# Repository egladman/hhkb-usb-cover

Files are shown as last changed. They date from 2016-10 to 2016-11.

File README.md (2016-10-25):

# HHKB USB Cover

[3D View](https://github.com/egladman/hhkb-usb-cover/blob/master/usb_cover.stl)

<br>

This is a cover for each of the unused usb ports on the Happy Hacking Keyboard with Hasu's controller.

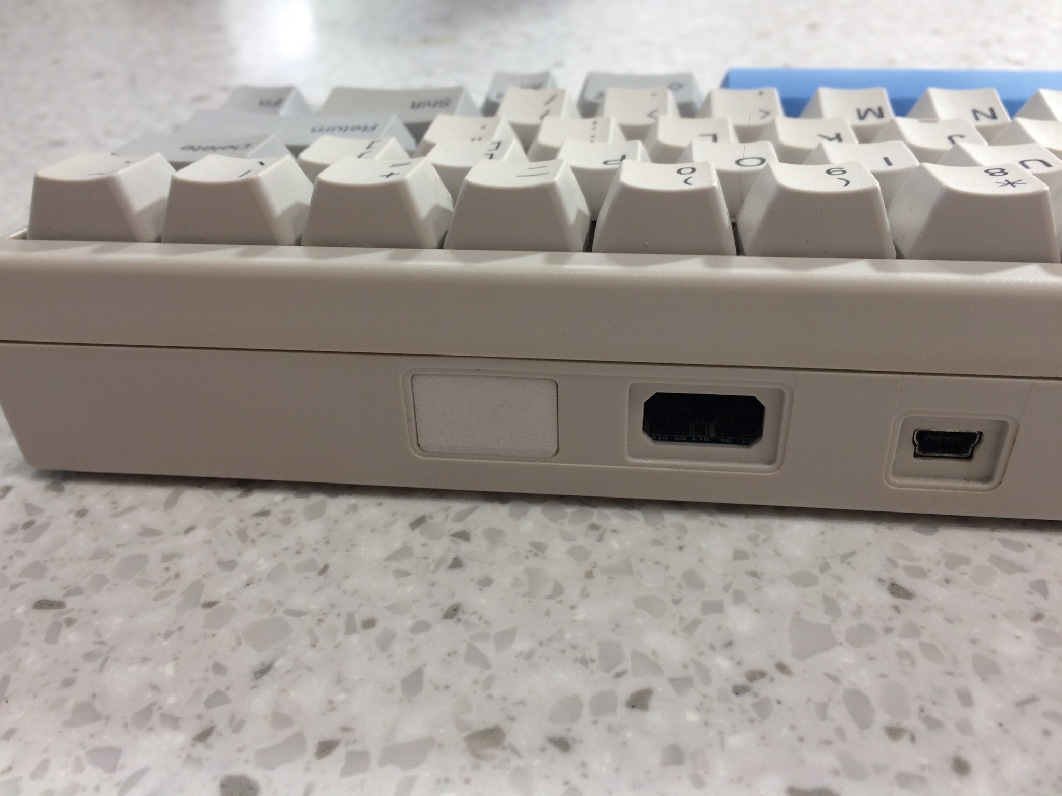
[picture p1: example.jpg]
HHKB USB Cover


<br>

Contributions/Suggestions are welcome!

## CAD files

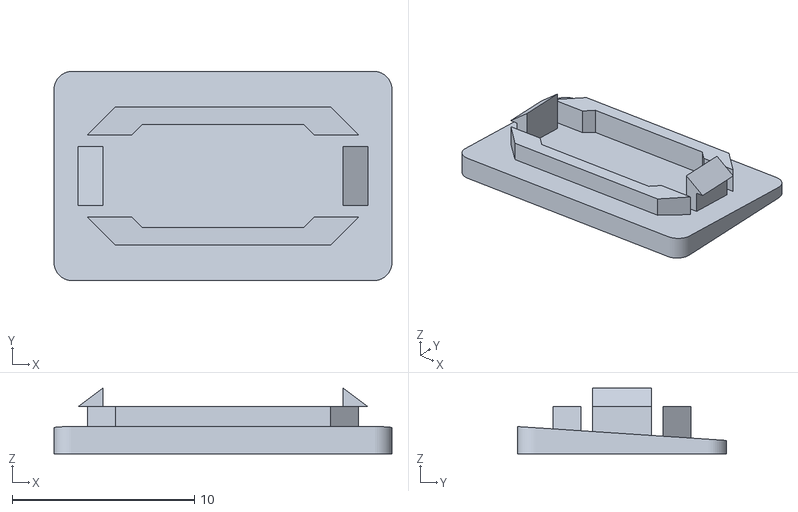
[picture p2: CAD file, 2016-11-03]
usb_cover.stl
18.6 x 11.5 x 3.61

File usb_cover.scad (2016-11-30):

outerWidth = 18.56;
outerHeight = 11.49;

innerWidth = 14.90;
innerHeight = 7.57;

widthDiff = (outerWidth - innerWidth)/2;
heightDiff = (outerHeight - innerHeight)/2;

radius = 1;

plugDepth = 1.75; 

translate([0,outerHeight,.85])
rotate([90,0,0])
cover();

module cover(){
difference() {
  $fn=50;
  translate([radius,0,radius])
  minkowski() {
   cube([outerWidth-(radius * 2),1.70, outerHeight- (radius * 2)], 0);

   rotate([90,0,0])
   cylinder(r=radius,h=1.70, center=true);
  }

  translate([(outerWidth-1)/2,2.10,outerHeight/2])
  rotate([-3.8,0,0])
  cube([outerWidth+2,3.65, outerHeight+10], center=true);
}

translate([widthDiff-.5,plugDepth,(outerHeight/2)])
clip();

translate([-widthDiff+.5+outerWidth,plugDepth,(outerHeight/2)])
rotate([0,180,0])
clip();

difference() {
  octogon();
    
  translate([outerWidth/8,0,outerHeight/8])
  scale(0.75)
  resize([0,10,0])
  octogon();
 
  translate([outerWidth/2,1.75,outerHeight/2])
  cube([13.2, 5, 3.5], center=true);
    
  translate([outerWidth/2,1.75,(outerHeight/2)+1.935])
  cube([16, 5, .625], center=true);
    
  translate([outerWidth/2,1.75,(outerHeight/2)-1.935])
  cube([16, 5, .625], center=true);
}


}

module octogon(){
  difference() {
    translate([widthDiff,0,heightDiff])
    cube([innerWidth,plugDepth, innerHeight], 0);

    len = 2.18;

    translate([widthDiff,0,heightDiff])
    rotate([0,45,0])
    cube([len, 25, len], center=true);

    translate([widthDiff,0,heightDiff+innerHeight])
    rotate([0,45,0])
    cube([len, 25, len], center=true);

    translate([widthDiff+innerWidth,0,heightDiff+innerHeight])
    rotate([0,45,0])
    cube([len, 25, len], center=true);

    translate([widthDiff+innerWidth,0,heightDiff])
    rotate([0,45,0])
    cube([len, 25, len], center=true);
  }
}

module clip(){
  difference(){
    resize([2,1.5,3.25])
    rotate([90,0,90])
    polyhedron ( points = [[0, -1, 3], [0, 1, 3], [0, 1, 0], [0, -1, 0], [3, -1, 3], [3, 1, 3]], 
    faces = [[0,3,2], [0,2,1], [3,0,4], [1,2,5], [0,5,4], [0,1,5],  [5,2,4], [4,2,3], ]);
  
    translate([3.35,0,0])
    cube([4, 4, 10], center=true);  
  }
}

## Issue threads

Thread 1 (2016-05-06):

add retaining clips to plug

egladman, 2016-05-06:
it would be great if I added some sort of retaining clips to the plugs to ensure they stay flush with the case

egladman, 2016-10-25:
so after printing this once i no longer think that retaining clips are needed.

egladman, 2016-10-28:
i ended up adding them 2b2ae7a7a53ebdc9f9e6a21ebc16ebe4d2ef6ed8

Closed 2016-10-25.

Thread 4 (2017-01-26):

What material to use?

rvanginneken, 2017-01-26:
Hey egladman,

I'm about to send this to a 3D printer, but I'm wondering what material you'd advise to use? Currently I'm looking at "rubber-like".

Also, can you give some info how snug it will fit? I'm using the board on different places and the covers need to stay in place. They should be removable somehow tho, to get to the reset button.

Looking forward to your feedback!

egladman, 2017-01-27:
I've had success printing the covers in abs and pla. The covers fit like a glove, to remove them you must open up your hhkb and pop them out from the other side.

rvanginneken, 2017-01-30:
Thanks for the info!
I wasn't aware that the reset button is behind the already removable slide cover, so it's perfect if they "fit like a glove". :)

I asked a friend with a home printer to print them for me, ordering them was getting a bit expensive in total. I'll update when I get them.

tengg, 2017-05-01:
I used PLA 100 micron, but it breaks when plugin.
What resolution do you use?

egladman, 2017-05-01:
That 's unfortunate :worried:. I print at 200. PLA is known to be brittle, however I haven't experienced any issues on my end.

tengg, 2017-05-01:
The print I have probably not from a very good 3d printer.
Do you know which material is more durable? ABS?

egladman, 2017-05-01:
I mean ABS is technically more durable. The issue with ABS is that prints sometimes warp due to the heat from the bed.

Closed 2017-06-13.

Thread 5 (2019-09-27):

Shapeways error

giammin, 2019-09-27:
Hi,

I uploaded yourmodel on shapeways and had this error.

> Unfortunately, the model you recently uploaded usb_cover did not pass our initial printability checks, so it's not yet ready for 3D printing. Printability Error:
> STL positions outside sane range. Likely STL ASCII file with no solid keyword

I dont know anything about 3d modelling and wonder if you could help.

Another thing: measures are mm or inch?

egladman, 2019-09-27:
Hey @giammin,

It's been so long time since I've worked on this, but I'll do my best to help. I'm currently traveling so I don't have access to a computer, otherwise I'd play around with the compiled STL.

Years prior I had Shapeways print this model during early testing. They might've changed print requirements since I last used them. Or maybe the print material is incompatible due to tolerances.

Measurements are in millimeters.

giammin, 2019-09-27:
thank you very much!

egladman, 2019-11-12:
@giammin did you ever figure it out? If not I'd suggest trying the STL from d1ba2702c2e38df9d22610d7d844e089ca2c2a09 before i reoriented the model.

giammin, 2019-11-14:
Thanks! That version works with shapeways.

The problem is that the cheapest is 9$ each without shipping

Did not expect it was so expensive.

Closed 2019-11-14.

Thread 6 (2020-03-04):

Reorient Print

egladman, 2020-03-04:
Originally reported in #5

The current solution is to use the STL compiled in a prior commit: https://github.com/egladman/hhkb-usb-cover/commit/d1ba2702c2e38df9d22610d7d844e089ca2c2a09

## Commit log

2016-05-06 created inital model
    [usb_cover.scad, usb_cover.stl]
2016-05-06 reduce plastic consumption
    [usb_cover.scad, usb_cover.stl]
2016-05-06 reduced thickness of cover
    [usb_cover.scad, usb_cover.stl]
2016-05-06 added link to stl
2016-10-25 revised design after the initial print
    [usb_cover.scad, usb_cover.stl]
2016-10-27 added retaining clips
    [usb_cover.scad, usb_cover.stl]
2016-11-03 compile stl
    [usb_cover.stl]
2016-11-03 reorient model
    [usb_cover.scad]
2016-11-03 recompile stl
    [usb_cover.stl]
